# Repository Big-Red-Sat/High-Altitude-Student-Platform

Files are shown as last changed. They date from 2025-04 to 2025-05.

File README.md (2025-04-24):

This repository contains the trials and tribulations UNL's Aerospace eXperimental Payload (AXP) team has gone through for the National Aeronautics and Space Administration (NASA) 
and Louisiana State University's (LSU) High Altitude Student Platform (HASP) program. AXP partnered with the National Renewable Energy Laboratory (NREL) to test their 
experimental solar cells called perovskite solar cells (PSCs).

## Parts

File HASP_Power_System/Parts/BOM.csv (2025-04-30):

Reference | Qty | Value | Footprint | Datasheet
C1 | 1 | 10uF | Capacitor_SMD:C_1210_3225Metric
C2 | 1 | 100nF | Capacitor_SMD:C_0805_2012Metric
C3 | 1 | KRM55TR71H226MH01K | KRM55TR71H226MH01K:CAPC6153X500N
C4 | 1 | 10uF | Capacitor_SMD:C_1206_3216Metric
C5 | 1 | 0.47uF | Capacitor_SMD:C_0805_2012Metric
C6 | 1 | 33uF | Capacitor_SMD:C_1206_3216Metric | https://www.digikey.com/en/products/detail/kyocera-avx/TPSA336K006R0600/563859
C7,C8 | 2 | 0.1u | Capacitor_SMD:C_0805_2012Metric
D1 | 1 | D_Schottky | mcp16301:schottky_diode_B140-13-F
D2 | 1 | 1N4148 | Diode_SMD:D_SOD-323
J1,J2,J3,J4,J7 | 5 | Conn_01x02 | Connector_Molex:Molex_PicoBlade_53047-0210_1x02_P1.25mm_Vertical
J5 | 1 | Conn_01x02 | Connector_PinHeader_2.54mm:PinHeader_1x02_P2.54mm_Horizontal
J6 | 1 | Conn_01x04 | Connector_Molex:Molex_PicoBlade_53047-0410_1x04_P1.25mm_Vertical
L1 | 1 | 1231AS-H-150M=P3 | 1231AS_H_150M_P3:IND_1231AS-H-150M=P3
R1 | 1 | 51.2k | Resistor_SMD:R_0805_2012Metric
R2 | 1 | 10k | Resistor_SMD:R_0805_2012Metric
U1 | 1 | mcp16301 | mcp16301:mcp16301
U2 | 1 | LM3940IMPX-3.3/NOPB | MP04A | LM3940IMPX-3.3/NOPB
U3 | 1 | Teensy4.1 | Teensy:Teensy41

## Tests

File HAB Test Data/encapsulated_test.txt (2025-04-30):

Created file at epoch: 1157
(Timestamp: 1160) Temperature Readings: [35.48, 30.32, 244.19, 32.90, 31.61, -26.13, 33.23, -21.94], Solar Cell 1: [Voltage: 0.00V, Current: 0.33mA], Solar Cell 2: [Voltage: 0.04V, Current: 0.65mA]
(Timestamp: 1662) Temperature Readings: [20.00, 32.26, 30.97, 26.77, 25.48, 25.16, 30.65, 25.48], Solar Cell 1: [Voltage: 0.00V, Current: 0.65mA], Solar Cell 2: [Voltage: 0.03V, Current: 0.98mA]
(Timestamp: 2164) Temperature Readings: [20.32, 25.16, 30.97, 24.52, 31.29, 27.42, 25.48, 27.74], Solar Cell 1: [Voltage: 0.00V, Current: 0.65mA], Solar Cell 2: [Voltage: 0.04V, Current: 0.65mA]
(Timestamp: 2667) Temperature Readings: [12.58, 37.42, 30.65, 26.13, 28.39, 26.77, 30.32, 26.77], Solar Cell 1: [Voltage: 0.00V, Current: 0.65mA], Solar Cell 2: [Voltage: 0.03V, Current: 0.98mA]
(Timestamp: 3169) Temperature Readings: [28.39, 17.74, 31.29, 25.16, 26.13, 29.03, 25.81, 25.81], Solar Cell 1: [Voltage: 0.00V, Current: 0.65mA], Solar Cell 2: [Voltage: 0.04V, Current: 0.65mA]
(Timestamp: 3672) Temperature Readings: [14.19, 34.19, 30.65, 25.81, 28.39, 26.77, 28.71, 25.81], Solar Cell 1: [Voltage: 0.00V, Current: 0.65mA], Solar Cell 2: [Voltage: 0.04V, Current: 0.65mA]
(Timestamp: 4174) Temperature Readings: [12.58, 33.23, 30.00, 25.16, 30.65, 26.45, 27.10, 25.48], Solar Cell 1: [Voltage: 0.00V, Current: 0.65mA], Solar Cell 2: [Voltage: 0.04V, Current: 0.98mA]
(Timestamp: 4677) Temperature Readings: [38.71, 18.39, 29.35, 25.48, 24.84, 27.10, 25.48, 24.84], Solar Cell 1: [Voltage: 0.01V, Current: 0.65mA], Solar Cell 2: [Voltage: 0.04V, Current: 0.98mA]
(Timestamp: 5180) Temperature Readings: [16.13, 30.32, 29.35, 24.52, 32.26, 26.13, 26.13, 25.48], Solar Cell 1: [Voltage: 0.00V, Current: 0.65mA], Solar Cell 2: [Voltage: 0.04V, Current: 0.65mA]
(Timestamp: 5682) Temperature Readings: [11.29, 42.90, 29.35, 25.81, 28.71, 25.48, 29.35, 24.84], Solar Cell 1: [Voltage: 0.00V, Current: 0.65mA], Solar Cell 2: [Voltage: 0.03V, Current: 0.65mA]
(Timestamp: 6185) Temperature Readings: [18.06, 28.06, 30.32, 24.84, 31.61, 26.77, 26.13, 25.48], Solar Cell 1: [Voltage: 0.00V, Current: 0.65mA], Solar Cell 2: [Voltage: 0.04V, Current: 0.98mA]
(Timestamp: 6691) Temperature Readings: [36.13, 24.19, 29.35, 27.10, 24.84, 26.45, 26.77, 24.19], Solar Cell 1: [Voltage: 0.00V, Current: 0.65mA], Solar Cell 2: [Voltage: 0.04V, Current: 0.98mA]
(Timestamp: 7193) Temperature Readings: [22.58, 19.68, 29.03, 24.84, 28.06, 25.81, 25.48, 24.84], Solar Cell 1: [Voltage: 0.00V, Current: 0.65mA], Solar Cell 2: [Voltage: 0.04V, Current: 0.65mA]
(Timestamp: 7696) Temperature Readings: [16.77, 38.06, 28.39, 26.45, 25.81, 23.87, 29.68, 24.19], Solar Cell 1: [Voltage: 0.00V, Current: 0.65mA], Solar Cell 2: [Voltage: 0.04V, Current: 0.98mA]
(Timestamp: 8198) Temperature Readings: [17.74, 38.06, 28.39, 26.77, 25.81, 23.87, 29.03, 23.55], Solar Cell 1: [Voltage: 0.00V, Current: 0.65mA], Solar Cell 2: [Voltage: 0.04V, Current: 0.65mA]
(Timestamp: 8701) Temperature Readings: [11.29, 42.26, 29.35, 26.13, 27.74, 26.13, 29.35, 28.39], Solar Cell 1: [Voltage: 1.99V, Current: 3.26mA], Solar Cell 2: [Voltage: 0.97V, Current: 85.22mA]
(Timestamp: 9204) Temperature Readings: [21.61, 26.77, 29.35, 26.77, 25.16, 24.52, 29.68, 24.19], Solar Cell 1: [Voltage: 2.12V, Current: 3.92mA], Solar Cell 2: [Voltage: 1.72V, Current: 4.24mA]
(Timestamp: 9706) Temperature Readings: [28.71, 21.61, 30.00, 24.84, 27.42, 26.45, 27.10, 25.48], Solar Cell 1: [Voltage: 2.60V, Current: 4.24mA], Solar Cell 2: [Voltage: 2.48V, Current: 5.22mA]
(Timestamp: 10209) Temperature Readings: [38.71, 18.39, 29.03, 25.16, 27.10, 26.13, 27.10, 24.52], Solar Cell 1: [Voltage: 2.61V, Current: 4.24mA], Solar Cell 2: [Voltage: 2.10V, Current: 4.90mA]
(Timestamp: 10711) Temperature Readings: [17.74, 26.13, 27.74, 25.48, 29.35, 25.16, 25.81, 24.19], Solar Cell 1: [Voltage: 1.99V, Current: 3.26mA], Solar Cell 2: [Voltage: 0.57V, Current: 38.20mA]
(Timestamp: 11213) Temperature Readings: [36.77, 21.61, 28.06, 26.77, 24.19, 24.19, 26.77, 23.55], Solar Cell 1: [Voltage: 2.50V, Current: 4.24mA], Solar Cell 2: [Voltage: 2.29V, Current: 5.22mA]
(Timestamp: 11716) Temperature Readings: [29.35, 27.10, 27.74, 27.10, 25.16, 24.52, 27.42, 23.87], Solar Cell 1: [Voltage: 2.74V, Current: 4.24mA], Solar Cell 2: [Voltage: 2.50V, Current: 5.55mA]
(Timestamp: 12222) Temperature Readings: [20.32, 29.35, 29.35, 24.84, 31.29, 25.48, 25.81, 24.52], Solar Cell 1: [Voltage: 2.44V, Current: 4.24mA], Solar Cell 2: [Voltage: 2.14V, Current: 5.22mA]
(Timestamp: 12724) Temperature Readings: [33.87, 21.29, 29.35, 26.45, 24.84, 25.48, 25.81, 24.19], Solar Cell 1: [Voltage: 2.74V, Current: 4.24mA], Solar Cell 2: [Voltage: 2.54V, Current: 5.55mA]
(Timestamp: 13226) Temperature Readings: [22.26, 32.58, 28.39, 26.77, 26.13, 25.16, 28.39, 23.87], Solar Cell 1: [Voltage: 2.72V, Current: 4.24mA], Solar Cell 2: [Voltage: 2.17V, Current: 4.90mA]
(Timestamp: 13729) Temperature Readings: [18.71, 26.45, 27.74, 25.16, 29.03, 24.52, 25.48, 24.19], Solar Cell 1: [Voltage: 2.05V, Current: 3.59mA], Solar Cell 2: [Voltage: 0.64V, Current: 47.02mA]
(Timestamp: 14232) Temperature Readings: [35.81, 25.16, 27.42, 27.42, 25.48, 24.84, 28.06, 23.55], Solar Cell 1: [Voltage: 2.65V, Current: 4.24mA], Solar Cell 2: [Voltage: 2.43V, Current: 5.55mA]
(Timestamp: 14734) Temperature Readings: [16.77, 36.77, 28.06, 25.48, 29.03, 24.52, 27.74, 24.52], Solar Cell 1: [Voltage: 2.80V, Current: 4.24mA], Solar Cell 2: [Voltage: 2.54V, Current: 5.55mA]
(Timestamp: 15237) Temperature Readings: [21.61, 23.55, 29.03, 24.84, 30.32, 25.48, 25.48, 27.42], Solar Cell 1: [Voltage: 2.49V, Current: 3.92mA], Solar Cell 2: [Voltage: 0.95V, Current: 82.93mA]
(Timestamp: 15739) Temperature Readings: [14.84, 32.26, 28.71, 24.84, 29.68, 24.52, 27.10, 24.19], Solar Cell 1: [Voltage: 2.43V, Current: 4.24mA], Solar Cell 2: [Voltage: 1.75V, Current: 4.57mA]
(Timestamp: 16242) Temperature Readings: [41.29, 21.61, 28.71, 25.48, 25.81, 25.48, 26.77, 24.19], Solar Cell 1: [Voltage: 2.79V, Current: 4.57mA], Solar Cell 2: [Voltage: 2.15V, Current: 4.90mA]
(Timestamp: 16744) Temperature Readings: [34.19, 15.48, 28.39, 25.16, 25.81, 25.81, 25.48, 23.87], Solar Cell 1: [Voltage: 2.74V, Current: 4.57mA], Solar Cell 2: [Voltage: 1.82V, Current: 4.57mA]
(Timestamp: 17247) Temperature Readings: [20.32, 34.52, 26.77, 26.13, 26.45, 22.58, 29.68, 23.23], Solar Cell 1: [Voltage: 2.09V, Current: 3.92mA], Solar Cell 2: [Voltage: 0.75V, Current: 61.06mA]
(Timestamp: 17750) Temperature Readings: [34.19, 25.81, 27.10, 26.45, 25.16, 23.55, 27.42, 22.58], Solar Cell 1: [Voltage: 2.71V, Current: 4.24mA], Solar Cell 2: [Voltage: 2.06V, Current: 4.90mA]
(Timestamp: 18256) Temperature Readings: [12.90, 36.45, 28.06, 25.48, 31.29, 24.52, 27.42, 24.52], Solar Cell 1: [Voltage: 2.08V, Current: 3.92mA], Solar Cell 2: [Voltage: 0.69V, Current: 53.22mA]
(Timestamp: 18758) Temperature Readings: [31.94, 21.29, 28.71, 26.77, 25.48, 24.52, 26.45, 23.23], Solar Cell 1: [Voltage: 2.70V, Current: 4.24mA], Solar Cell 2: [Voltage: 2.00V, Current: 4.90mA]
(Timestamp: 19261) Temperature Readings: [39.03, 19.35, 28.39, 26.77, 25.81, 24.52, 26.77, 23.23], Solar Cell 1: [Voltage: 2.82V, Current: 4.57mA], Solar Cell 2: [Voltage: 2.00V, Current: 4.57mA]
(Timestamp: 19763) Temperature Readings: [34.52, 25.16, 27.10, 26.77, 25.48, 23.87, 28.06, 23.87], Solar Cell 1: [Voltage: 2.46V, Current: 3.92mA], Solar Cell 2: [Voltage: 0.86V, Current: 71.50mA]
(Timestamp: 20266) Temperature Readings: [27.10, 28.06, 26.77, 27.42, 25.16, 22.90, 28.06, 22.58], Solar Cell 1: [Voltage: 2.49V, Current: 4.24mA], Solar Cell 2: [Voltage: 1.82V, Current: 4.57mA]
(Timestamp: 20768) Temperature Readings: [15.16, 32.90, 27.42, 26.13, 31.94, 22.90, 27.74, 23.55], Solar Cell 1: [Voltage: 2.79V, Current: 4.57mA], Solar Cell 2: [Voltage: 2.14V, Current: 4.90mA]
(Timestamp: 21271) Temperature Readings: [37.42, 21.29, 28.06, 25.16, 23.23, 23.23, 26.13, 23.23], Solar Cell 1: [Voltage: 2.77V, Current: 4.24mA], Solar Cell 2: [Voltage: 1.94V, Current: 4.90mA]
(Timestamp: 21773) Temperature Readings: [14.84, 37.42, 27.42, 26.13, 27.74, 22.90, 29.35, 23.23], Solar Cell 1: [Voltage: 2.17V, Current: 3.59mA], Solar Cell 2: [Voltage: 0.59V, Current: 39.18mA]
(Timestamp: 22276) Temperature Readings: [12.26, 32.26, 28.39, 25.16, 31.29, 23.55, 27.10, 23.55], Solar Cell 1: [Voltage: 2.63V, Current: 4.24mA], Solar Cell 2: [Voltage: 1.97V, Current: 4.57mA]
(Timestamp: 22778) Temperature Readings: [25.16, 21.61, 28.71, 24.84, 29.03, 24.84, 26.45, 23.87], Solar Cell 1: [Voltage: 2.81V, Current: 4.57mA], Solar Cell 2: [Voltage: 2.06V, Current: 4.90mA]
(Timestamp: 23280) Temperature Readings: [38.06, 24.52, 27.10, 27.74, 24.52, 23.55, 26.77, 22.58], Solar Cell 1: [Voltage: 2.70V, Current: 4.24mA], Solar Cell 2: [Voltage: 1.61V, Current: 4.24mA]
(Timestamp: 23783) Temperature Readings: [30.32, 17.74, 26.77, 25.16, 25.48, 23.87, 25.81, 23.23], Solar Cell 1: [Voltage: 2.08V, Current: 3.92mA], Solar Cell 2: [Voltage: 0.77V, Current: 63.34mA]
(Timestamp: 24289) Temperature Readings: [23.55, 17.74, 27.74, 24.84, 27.42, 23.55, 24.84, 23.23], Solar Cell 1: [Voltage: 2.74V, Current: 4.24mA], Solar Cell 2: [Voltage: 1.81V, Current: 4.57mA]
(Timestamp: 24791) Temperature Readings: [11.61, 42.26, 27.74, 26.13, 27.74, 22.90, 29.03, 23.55], Solar Cell 1: [Voltage: 2.06V, Current: 3.92mA], Solar Cell 2: [Voltage: 0.70V, Current: 55.18mA]
(Timestamp: 25294) Temperature Readings: [13.23, 30.00, 28.06, 26.13, 30.32, 24.19, 27.10, 23.87], Solar Cell 1: [Voltage: 2.69V, Current: 4.24mA], Solar Cell 2: [Voltage: 2.52V, Current: 5.55mA]
(Timestamp: 25796) Temperature Readings: [36.45, 23.23, 27.74, 25.81, 25.48, 24.84, 27.74, 23.55], Solar Cell 1: [Voltage: 2.79V, Current: 4.57mA], Solar Cell 2: [Voltage: 2.62V, Current: 5.55mA]
(Timestamp: 26299) Temperature Readings: [16.13, 26.77, 26.77, 25.48, 29.35, 22.90, 26.13, 24.52], Solar Cell 1: [Voltage: 2.45V, Current: 3.92mA], Solar Cell 2: [Voltage: 0.95V, Current: 82.93mA]
(Timestamp: 26802) Temperature Readings: [33.23, 28.71, 26.13, 26.77, 24.84, 22.26, 26.77, 21.29], Solar Cell 1: [Voltage: 2.43V, Current: 4.24mA], Solar Cell 2: [Voltage: 2.05V, Current: 4.90mA]
(Timestamp: 27304) Temperature Readings: [37.74, 23.23, 26.77, 26.13, 23.87, 22.90, 25.81, 22.90], Solar Cell 1: [Voltage: 2.74V, Current: 4.57mA], Solar Cell 2: [Voltage: 2.66V, Current: 5.55mA]
(Timestamp: 27807) Temperature Readings: [13.87, 32.58, 27.10, 25.16, 30.65, 22.90, 26.45, 23.23], Solar Cell 1: [Voltage: 0.96V, Current: 99.91mA], Solar Cell 2: [Voltage: 2.07V, Current: 4.90mA]
(Timestamp: 28309) Temperature Readings: [12.26, 35.16, 27.42, 25.48, 30.97, 22.90, 27.74, 23.55], Solar Cell 1: [Voltage: 0.78V, Current: 85.22mA], Solar Cell 2: [Voltage: 0.76V, Current: 62.36mA]
(Timestamp: 28812) Temperature Readings: [14.84, 32.58, 27.74, 25.81, 31.29, 24.19, 26.77, 23.87], Solar Cell 1: [Voltage: 1.00V, Current: 111.66mA], Solar Cell 2: [Voltage: 2.31V, Current: 5.22mA]
(Timestamp: 29314) Temperature Readings: [38.06, 17.74, 27.74, 25.48, 24.84, 23.55, 25.81, 23.23], Solar Cell 1: [Voltage: 1.06V, Current: 111.99mA], Solar Cell 2: [Voltage: 2.19V, Current: 4.90mA]
(Timestamp: 29817) Temperature Readings: [30.65, 15.81, 26.77, 25.16, 25.81, 23.55, 25.81, 23.87], Solar Cell 1: [Voltage: 0.89V, Current: 87.18mA], Solar Cell 2: [Voltage: 0.85V, Current: 71.18mA]
(Timestamp: 30323) Temperature Readings: [39.35, 20.32, 26.77, 26.13, 24.19, 22.90, 25.48, 22.26], Solar Cell 1: [Voltage: 1.06V, Current: 111.99mA], Solar Cell 2: [Voltage: 2.37V, Current: 5.22mA]
(Timestamp: 30826) Temperature Readings: [34.52, 25.81, 27.10, 26.77, 24.84, 23.23, 27.10, 23.23], Solar Cell 1: [Voltage: 0.90V, Current: 88.48mA], Solar Cell 2: [Voltage: 0.89V, Current: 75.75mA]
(Timestamp: 31328) Temperature Readings: [23.23, 32.58, 27.10, 26.77, 24.84, 22.26, 28.71, 22.26], Solar Cell 1: [Voltage: 0.90V, Current: 107.09mA], Solar Cell 2: [Voltage: 1.81V, Current: 4.57mA]
(Timestamp: 31830) Temperature Readings: [21.61, 20.32, 28.39, 24.52, 28.39, 23.55, 25.48, 23.55], Solar Cell 1: [Voltage: 1.05V, Current: 108.40mA], Solar Cell 2: [Voltage: 2.39V, Current: 5.22mA]
(Timestamp: 32333) Temperature Readings: [27.42, 21.94, 27.42, 25.48, 27.74, 23.23, 26.45, 23.23], Solar Cell 1: [Voltage: 1.06V, Current: 111.01mA], Solar Cell 2: [Voltage: 2.23V, Current: 4.90mA]
(Timestamp: 32835) Temperature Readings: [28.06, 16.45, 26.45, 24.84, 27.10, 22.90, 26.45, 22.26], Solar Cell 1: [Voltage: 0.83V, Current: 80.32mA], Solar Cell 2: [Voltage: 0.59V, Current: 40.16mA]
(Timestamp: 33338) Temperature Readings: [26.45, 21.61, 26.45, 25.48, 24.84, 22.58, 25.48, 22.90], Solar Cell 1: [Voltage: 0.95V, Current: 110.68mA], Solar Cell 2: [Voltage: 2.17V, Current: 4.90mA]
(Timestamp: 33840) Temperature Readings: [17.10, 36.77, 26.45, 25.48, 31.61, 21.29, 29.35, 22.58], Solar Cell 1: [Voltage: 1.06V, Current: 95.01mA], Solar Cell 2: [Voltage: 2.42V, Current: 5.22mA]
(Timestamp: 34343) Temperature Readings: [36.13, 25.16, 27.10, 26.13, 25.16, 22.58, 25.81, 20.97], Solar Cell 1: [Voltage: 1.02V, Current: 105.46mA], Solar Cell 2: [Voltage: 1.83V, Current: 4.57mA]
(Timestamp: 34845) Temperature Readings: [25.81, 21.94, 27.74, 25.48, 28.39, 24.19, 26.45, 24.84], Solar Cell 1: [Voltage: 0.83V, Current: 95.99mA], Solar Cell 2: [Voltage: 1.04V, Current: 96.64mA]
(Timestamp: 35348) Temperature Readings: [22.58, 32.58, 27.42, 26.13, 26.45, 21.61, 28.71, 22.58], Solar Cell 1: [Voltage: 1.04V, Current: 96.32mA], Solar Cell 2: [Voltage: 2.39V, Current: 5.22mA]
(Timestamp: 35854) Temperature Readings: [39.35, 23.87, 25.81, 26.77, 25.81, 22.58, 27.42, 23.55], Solar Cell 1: [Voltage: 0.81V, Current: 95.01mA], Solar Cell 2: [Voltage: 0.98V, Current: 89.46mA]
(Timestamp: 36356) Temperature Readings: [34.52, 16.13, 26.45, 26.45, 24.52, 22.58, 26.13, 22.90], Solar Cell 1: [Voltage: 1.04V, Current: 107.42mA], Solar Cell 2: [Voltage: 2.35V, Current: 5.22mA]
(Timestamp: 36859) Temperature Readings: [36.77, 20.00, 27.10, 24.84, 24.52, 22.58, 24.52, 21.94], Solar Cell 1: [Voltage: 1.07V, Current: 111.66mA], Solar Cell 2: [Voltage: 1.94V, Current: 4.57mA]
(Timestamp: 37362) Temperature Readings: [24.84, 14.84, 27.42, 25.16, 28.71, 23.23, 24.84, 22.90], Solar Cell 1: [Voltage: 0.85V, Current: 82.28mA], Solar Cell 2: [Voltage: 0.62V, Current: 43.10mA]
(Timestamp: 37864) Temperature Readings: [33.87, 24.84, 27.10, 26.45, 24.52, 22.58, 28.71, 22.26], Solar Cell 1: [Voltage: 0.98V, Current: 111.99mA], Solar Cell 2: [Voltage: 2.17V, Current: 4.90mA]
(Timestamp: 38367) Temperature Readings: [17.10, 41.61, 26.77, 26.13, 27.10, 21.61, 29.03, 22.26], Solar Cell 1: [Voltage: 1.08V, Current: 75.42mA], Solar Cell 2: [Voltage: 2.35V, Current: 5.22mA]
(Timestamp: 38869) Temperature Readings: [22.90, 23.23, 26.77, 25.16, 26.77, 22.58, 25.48, 22.58], Solar Cell 1: [Voltage: 0.97V, Current: 98.93mA], Solar Cell 2: [Voltage: 1.35V, Current: 61.71mA]
(Timestamp: 39372) Temperature Readings: [21.61, 31.94, 25.48, 26.45, 24.84, 20.97, 28.71, 21.61], Solar Cell 1: [Voltage: 0.89V, Current: 107.09mA], Solar Cell 2: [Voltage: 1.61V, Current: 4.24mA]
(Timestamp: 39874) Temperature Readings: [25.48, 21.94, 26.13, 26.45, 24.52, 22.90, 25.16, 22.26], Solar Cell 1: [Voltage: 1.07V, Current: 66.93mA], Solar Cell 2: [Voltage: 2.35V, Current: 5.22mA]
(Timestamp: 40377) Temperature Readings: [12.90, 39.68, 26.45, 25.81, 27.74, 21.29, 29.68, 22.26], Solar Cell 1: [Voltage: 1.04V, Current: 109.38mA], Solar Cell 2: [Voltage: 2.03V, Current: 4.57mA]
(Timestamp: 40880) Temperature Readings: [20.00, 25.48, 27.42, 24.84, 31.29, 22.26, 25.48, 23.23], Solar Cell 1: [Voltage: 0.81V, Current: 89.13mA], Solar Cell 2: [Voltage: 0.74V, Current: 59.75mA]
(Timestamp: 41382) Temperature Readings: [20.32, 27.74, 27.10, 24.84, 30.00, 22.58, 25.48, 23.23], Solar Cell 1: [Voltage: 1.03V, Current: 77.71mA], Solar Cell 2: [Voltage: 2.29V, Current: 5.22mA]
(Timestamp: 41888) Temperature Readings: [38.71, 19.35, 25.81, 25.16, 26.13, 21.94, 26.77, 22.58], Solar Cell 1: [Voltage: 0.81V, Current: 87.18mA], Solar Cell 2: [Voltage: 0.68V, Current: 52.89mA]
(Timestamp: 42390) Temperature Readings: [26.45, 15.81, 26.13, 25.16, 27.10, 22.26, 24.84, 22.26], Solar Cell 1: [Voltage: 1.01V, Current: 90.44mA], Solar Cell 2: [Voltage: 2.26V, Current: 5.22mA]
(Timestamp: 42893) Temperature Readings: [25.16, 21.29, 26.13, 25.48, 25.81, 21.94, 24.84, 21.29], Solar Cell 1: [Voltage: 1.08V, Current: 65.95mA], Solar Cell 2: [Voltage: 2.32V, Current: 5.22mA]
(Timestamp: 43395) Temperature Readings: [32.90, 15.48, 27.42, 25.48, 25.16, 23.55, 25.16, 24.84], Solar Cell 1: [Voltage: 0.95V, Current: 96.32mA], Solar Cell 2: [Voltage: 1.11V, Current: 99.91mA]
(Timestamp: 43898) Temperature Readings: [39.68, 19.35, 27.42, 25.81, 24.19, 22.26, 25.48, 22.26], Solar Cell 1: [Voltage: 0.88V, Current: 106.11mA], Solar Cell 2: [Voltage: 1.53V, Current: 4.57mA]
(Timestamp: 44400) Temperature Readings: [17.10, 32.90, 27.10, 25.81, 31.29, 21.94, 28.06, 22.58], Solar Cell 1: [Voltage: 1.06V, Current: 63.34mA], Solar Cell 2: [Voltage: 2.14V, Current: 4.90mA]
(Timestamp: 44903) Temperature Readings: [36.13, 28.39, 26.45, 26.77, 24.84, 22.26, 26.77, 21.61], Solar Cell 1: [Voltage: 1.06V, Current: 111.66mA], Solar Cell 2: [Voltage: 1.94V, Current: 4.57mA]
(Timestamp: 45405) Temperature Readings: [32.90, 24.19, 25.16, 27.10, 25.48, 21.29, 28.39, 20.97], Solar Cell 1: [Voltage: 0.80V, Current: 83.91mA], Solar Cell 2: [Voltage: 0.62V, Current: 44.08mA]
(Timestamp: 45908) Temperature Readings: [26.13, 19.03, 26.13, 25.16, 27.74, 21.94, 24.84, 22.26], Solar Cell 1: [Voltage: 1.02V, Current: 72.16mA], Solar Cell 2: [Voltage: 2.54V, Current: 5.55mA]
(Timestamp: 46410) Temperature Readings: [25.81, 30.00, 25.48, 26.77, 24.84, 20.32, 28.39, 21.29], Solar Cell 1: [Voltage: 1.08V, Current: 66.28mA], Solar Cell 2: [Voltage: 2.62V, Current: 5.55mA]
(Timestamp: 46913) Temperature Readings: [12.58, 40.32, 26.45, 25.81, 29.68, 21.94, 28.71, 22.90], Solar Cell 1: [Voltage: 0.90V, Current: 89.46mA], Solar Cell 2: [Voltage: 0.81V, Current: 65.95mA]
(Timestamp: 47415) Temperature Readings: [36.77, 18.71, 27.10, 25.48, 24.52, 22.26, 26.45, 22.58], Solar Cell 1: [Voltage: 0.95V, Current: 111.99mA], Solar Cell 2: [Voltage: 2.27V, Current: 5.22mA]
(Timestamp: 47922) Temperature Readings: [19.03, 37.10, 25.48, 26.45, 26.13, 20.65, 29.03, 21.94], Solar Cell 1: [Voltage: 0.86V, Current: 85.22mA], Solar Cell 2: [Voltage: 0.67V, Current: 48.65mA]
(Timestamp: 48424) Temperature Readings: [35.81, 20.32, 25.81, 25.16, 25.16, 22.26, 25.16, 21.94], Solar Cell 1: [Voltage: 0.97V, Current: 111.01mA], Solar Cell 2: [Voltage: 2.08V, Current: 4.90mA]
(Timestamp: 48927) Temperature Readings: [18.06, 30.32, 25.48, 25.81, 33.23, 20.97, 26.77, 21.61], Solar Cell 1: [Voltage: 1.08V, Current: 51.59mA], Solar Cell 2: [Voltage: 2.30V, Current: 5.22mA]
(Timestamp: 49429) Temperature Readings: [30.32, 13.23, 27.10, 25.16, 26.13, 22.26, 24.52, 23.23], Solar Cell 1: [Voltage: 0.97V, Current: 99.58mA], Solar Cell 2: [Voltage: 1.30V, Current: 115.58mA]
(Timestamp: 49932) Temperature Readings: [22.58, 23.23, 27.10, 25.16, 29.35, 22.26, 26.13, 22.58], Solar Cell 1: [Voltage: 0.90V, Current: 110.03mA], Solar Cell 2: [Voltage: 1.66V, Current: 4.24mA]
(Timestamp: 50434) Temperature Readings: [34.52, 19.68, 26.77, 26.13, 25.48, 22.90, 25.16, 21.61], Solar Cell 1: [Voltage: 1.08V, Current: 36.24mA], Solar Cell 2: [Voltage: 2.29V, Current: 5.22mA]
(Timestamp: 50937) Temperature Readings: [28.06, 28.39, 26.13, 27.10, 25.48, 21.61, 29.35, 21.61], Solar Cell 1: [Voltage: 1.05V, Current: 110.03mA], Solar Cell 2: [Voltage: 1.89V, Current: 4.57mA]
(Timestamp: 51440) Temperature Readings: [26.45, 19.68, 25.81, 25.48, 27.10, 21.94, 25.48, 22.90], Solar Cell 1: [Voltage: 0.82V, Current: 97.62mA], Solar Cell 2: [Voltage: 0.97V, Current: 89.46mA]
(Timestamp: 51942) Temperature Readings: [22.90, 25.16, 25.81, 24.84, 31.94, 21.29, 25.81, 21.61], Solar Cell 1: [Voltage: 1.05V, Current: 45.38mA], Solar Cell 2: [Voltage: 2.23V, Current: 4.90mA]
(Timestamp: 52444) Temperature Readings: [16.45, 30.97, 25.48, 26.13, 28.06, 20.65, 27.74, 21.29], Solar Cell 1: [Voltage: 1.09V, Current: 54.20mA], Solar Cell 2: [Voltage: 2.19V, Current: 4.90mA]
(Timestamp: 52947) Temperature Readings: [16.45, 30.00, 26.45, 24.84, 31.61, 21.94, 26.13, 23.55], Solar Cell 1: [Voltage: 0.90V, Current: 91.09mA], Solar Cell 2: [Voltage: 0.86V, Current: 70.85mA]
(Timestamp: 53453) Temperature Readings: [35.81, 21.61, 26.45, 26.45, 25.48, 22.26, 25.81, 20.97], Solar Cell 1: [Voltage: 1.08V, Current: 64.97mA], Solar Cell 2: [Voltage: 2.38V, Current: 5.22mA]
(Timestamp: 53955) Temperature Readings: [25.48, 18.39, 26.13, 24.84, 27.10, 21.61, 26.13, 22.90], Solar Cell 1: [Voltage: 0.91V, Current: 92.07mA], Solar Cell 2: [Voltage: 0.87V, Current: 72.81mA]
(Timestamp: 54457) Temperature Readings: [21.61, 29.35, 25.48, 24.84, 31.61, 20.97, 26.13, 21.94], Solar Cell 1: [Voltage: 0.92V, Current: 111.34mA], Solar Cell 2: [Voltage: 1.95V, Current: 4.57mA]
(Timestamp: 54960) Temperature Readings: [22.26, 20.00, 25.81, 25.16, 25.48, 21.61, 25.16, 21.94], Solar Cell 1: [Voltage: 1.08V, Current: 38.53mA], Solar Cell 2: [Voltage: 2.43V, Current: 5.22mA]
(Timestamp: 55462) Temperature Readings: [41.61, 21.29, 25.81, 26.13, 23.55, 21.61, 26.45, 20.97], Solar Cell 1: [Voltage: 1.00V, Current: 105.46mA], Solar Cell 2: [Voltage: 1.69V, Current: 4.24mA]
(Timestamp: 55965) Temperature Readings: [12.26, 35.16, 26.77, 24.84, 28.71, 22.26, 27.10, 24.19], Solar Cell 1: [Voltage: 0.85V, Current: 104.48mA], Solar Cell 2: [Voltage: 1.37V, Current: 19.92mA]
(Timestamp: 56468) Temperature Readings: [24.19, 29.03, 26.77, 25.48, 25.48, 20.97, 29.03, 21.29], Solar Cell 1: [Voltage: 1.06V, Current: 39.83mA], Solar Cell 2: [Voltage: 2.40V, Current: 5.22mA]
(Timestamp: 56970) Temperature Readings: [30.65, 29.68, 26.13, 27.10, 25.81, 21.29, 27.74, 21.61], Solar Cell 1: [Voltage: 1.06V, Current: 111.66mA], Solar Cell 2: [Voltage: 2.08V, Current: 4.90mA]
(Timestamp: 57473) Temperature Readings: [23.87, 23.55, 25.48, 25.16, 27.10, 20.97, 25.16, 22.26], Solar Cell 1: [Voltage: 0.80V, Current: 91.42mA], Solar Cell 2: [Voltage: 0.76V, Current: 63.01mA]
(Timestamp: 57975) Temperature Readings: [39.68, 27.10, 23.87, 26.45, 25.81, 21.29, 25.81, 20.00], Solar Cell 1: [Voltage: 1.05V, Current: 39.18mA], Solar Cell 2: [Voltage: 2.39V, Current: 5.22mA]
(Timestamp: 58478) Temperature Readings: [39.68, 18.06, 25.81, 25.81, 24.52, 21.29, 26.13, 21.29], Solar Cell 1: [Voltage: 1.08V, Current: 64.65mA], Solar Cell 2: [Voltage: 2.32V, Current: 5.22mA]
(Timestamp: 58981) Temperature Readings: [29.03, 12.58, 26.77, 25.48, 26.45, 21.94, 25.48, 22.26], Solar Cell 1: [Voltage: 0.84V, Current: 84.89mA], Solar Cell 2: [Voltage: 0.61V, Current: 41.14mA]
(Timestamp: 59487) Temperature Readings: [24.84, 30.32, 26.13, 26.13, 25.16, 20.65, 28.71, 21.94], Solar Cell 1: [Voltage: 1.08V, Current: 82.60mA], Solar Cell 2: [Voltage: 2.27V, Current: 5.22mA]
(Timestamp: 59989) Temperature Readings: [26.77, 28.39, 24.84, 27.10, 25.16, 20.97, 28.39, 20.97], Solar Cell 1: [Voltage: 0.81V, Current: 85.22mA], Solar Cell 2: [Voltage: 0.59V, Current: 40.49mA]
(Timestamp: 60492) Temperature Readings: [38.39, 19.03, 25.48, 25.48, 24.19, 20.97, 25.81, 21.29], Solar Cell 1: [Voltage: 1.03V, Current: 43.75mA], Solar Cell 2: [Voltage: 2.33V, Current: 5.22mA]
(Timestamp: 60994) Temperature Readings: [19.35, 29.68, 25.16, 25.16, 31.94, 21.94, 26.45, 22.26], Solar Cell 1: [Voltage: 1.09V, Current: 41.79mA], Solar Cell 2: [Voltage: 2.37V, Current: 5.22mA]
(Timestamp: 61497) Temperature Readings: [26.13, 16.13, 26.45, 25.16, 27.42, 22.26, 25.48, 22.58], Solar Cell 1: [Voltage: 0.87V, Current: 88.15mA], Solar Cell 2: [Voltage: 0.72V, Current: 54.20mA]
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

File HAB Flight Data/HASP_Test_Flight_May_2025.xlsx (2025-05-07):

Time Since Power On (ms) | Temperature Mounted on Module Inside Payload (C) | Temperature Encapsulated Inside Perovskite (C) | Temperature Internal on Perovskite Enclosure (C) | Temperature Outside Payload on Module Glass (C) | Temperature Behind Module On Aluminum (C) | SolarCell1 Voltage (V) | SolarCell1 Current (mA) | SolarCell2 Voltage (V) | SolarCell2 Current (mA)
1155 | 25.48 | 24.84 | 26.13 | 26.13 | 25.16 | 0.63 | 71.83 | 3.43 | 6.53
1672 | 19.68 | 19.03 | 20 | 19.68 | 19.68 | 0.66 | 77.71 | 3.45 | 6.86
2183 | 19.68 | 19.03 | 20 | 19.68 | 19.68 | 0.66 | 77.71 | 3.45 | 6.53
2694 | 19.68 | 19.03 | 20 | 20 | 19.68 | 0.71 | 83.26 | 3.46 | 6.86
3205 | 19.68 | 19.03 | 20 | 20 | 20 | 0.7 | 82.93 | 3.46 | 6.86
3716 | 19.68 | 18.71 | 20 | 20 | 19.68 | 0.72 | 85.54 | 3.44 | 6.53
4229 | 19.68 | 19.68 | 20.32 | 20.97 | 19.68 | 0.75 | 88.48 | 3.45 | 6.53
4742 | 19.68 | 19.35 | 20.32 | 20.97 | 20 | 0.71 | 84.56 | 3.48 | 6.53
5255 | 19.68 | 19.03 | 20 | 20.32 | 19.68 | 0.65 | 77.38 | 3.52 | 6.86
5769 | 19.68 | 19.03 | 20 | 20 | 19.68 | 0.57 | 68.56 | 3.54 | 6.86
6283 | 19.68 | 19.03 | 20 | 20.32 | 19.68 | 0.6 | 72.81 | 3.52 | 6.86
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

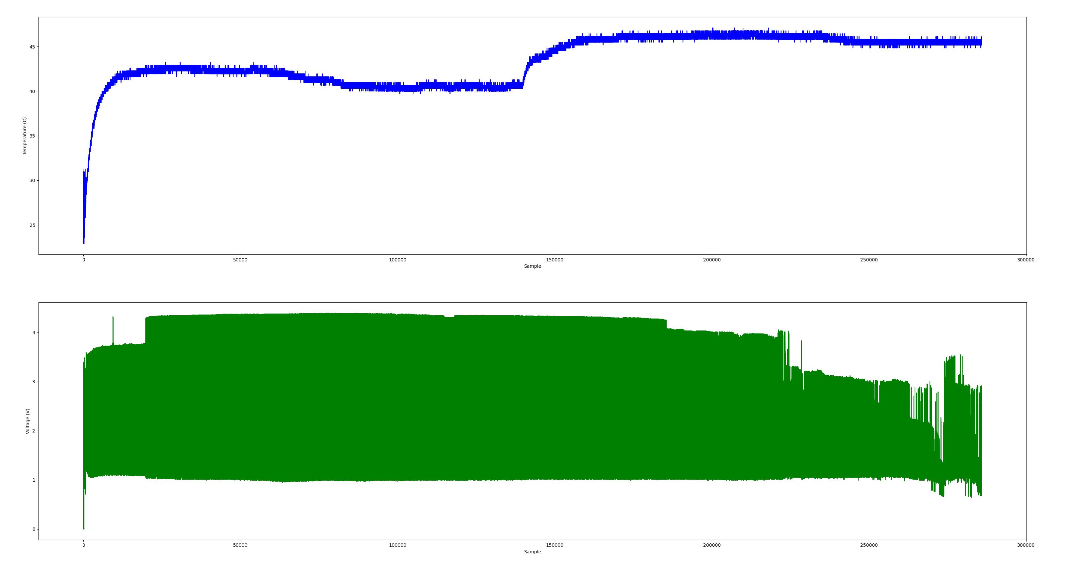
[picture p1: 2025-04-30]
HAB Test Data/Overnight_Test_Voltage_Temperature.png

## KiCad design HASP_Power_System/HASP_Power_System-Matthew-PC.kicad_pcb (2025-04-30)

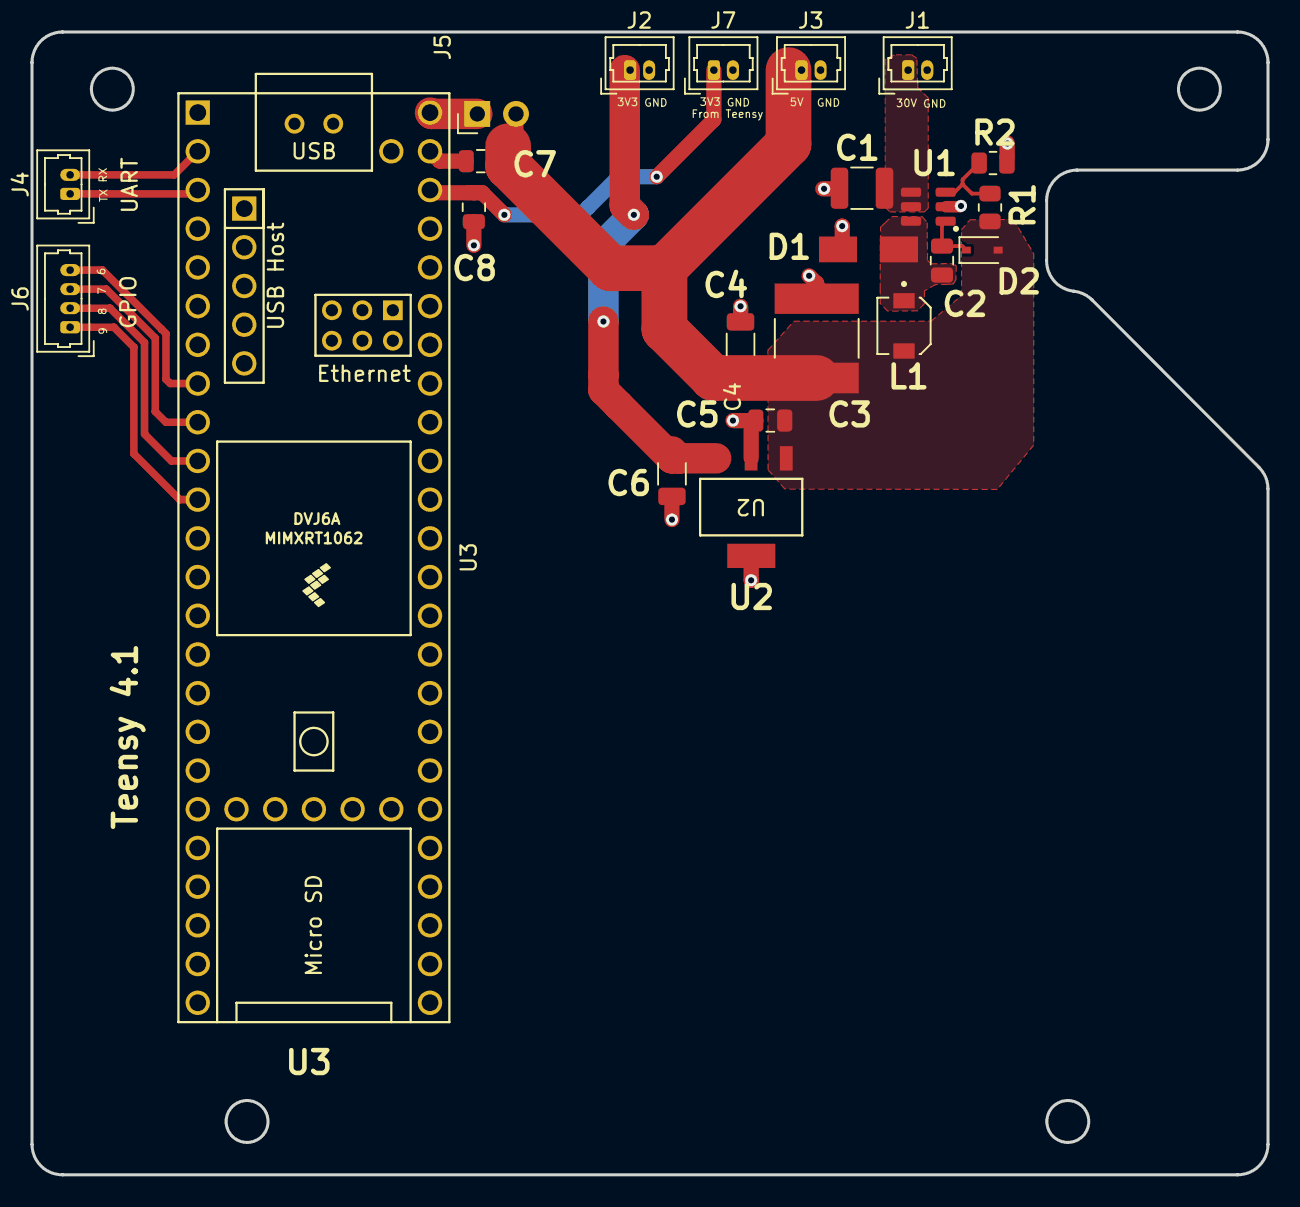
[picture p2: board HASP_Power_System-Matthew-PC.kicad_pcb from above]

Board: 2 copper layers, 81.1 x 75.0 mm, 23 parts (0 on the bottom side), 15 nets.

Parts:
C1: 10uF; C_1210_3225Metric
C2: 100nF; C_0805_2012Metric
C3: KRM55TR71H226MH01K; CAPC6153X500N
C4: 10uF; C_1206_3216Metric
C5: 0.47uF; C_0805_2012Metric
C6: 33uF; C_1206_3216Metric
C7, C8: 0.1u; C_0805_2012Metric
D1: D_Schottky; schottky_diode_B140-13-F
D2: 1N4148; D_SOD-323
J1, J2, J3, J4, J7: Conn_01x02; Molex_PicoBlade_53047-0210_1x02_P1.25mm_Vertical
J5: Conn_01x02; PinHeader_1x02_P2.54mm_Horizontal
J6: Conn_01x04; Molex_PicoBlade_53047-0410_1x04_P1.25mm_Vertical
L1: 1231AS-H-150M=P3; IND_1231AS-H-150M=P3
R1: 51.2k; R_0805_2012Metric
R2: 10k; R_0805_2012Metric
U1: mcp16301
U2: LM3940IMPX-3.3/NOPB; MP04A
U3: Teensy4.1; Teensy41

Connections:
+3V3_LDO: C6.1, J2.1, U2.3 (OUT)
+3V3_Teensy: C8.1, J7.1, U3.46 (3V3)
+5V: C3.1, C4.1, C5.1, C7.1, D2.2 (A), J3.1, J5.2, L1.2, R1.1, U2.1 (IN)
/SW_NODE: C2.2, D1.1 (K), L1.1, U1.6 (SW)
GND: C1.2, C3.2, C4.2, C5.2, C6.2, C7.2, C8.2, D1.2 (A), J1.2, J2.2, J3.2, J7.2, R2.2, U1.2 (GND), U2.2 (GND), U3.1 (GND), U3.34 (GND), U3.47 (GND)
GPIO1: J6.4, U3.8 (6_OUT1D)
GPIO2: J6.3, U3.9 (7_RX2_OUT1A)
GPIO3: J6.2, U3.10 (8_TX2_IN1)
GPIO4: J6.1, U3.11 (9_OUT1C)
unnamed: C2.1, D2.1 (K), U1.1 (Boost)
unnamed: J5.1, U3.48 (VIN)
unnamed: R1.2, R2.1, U1.3 (V_{FB})
RX: J4.2, U3.2 (0_RX1_CRX2_CS1)
TX: J4.1, U3.3 (1_TX1_CTX2_MISO1)
VCC_30: C1.1, J1.1, U1.4 (EN), U1.5 (V_{IN})

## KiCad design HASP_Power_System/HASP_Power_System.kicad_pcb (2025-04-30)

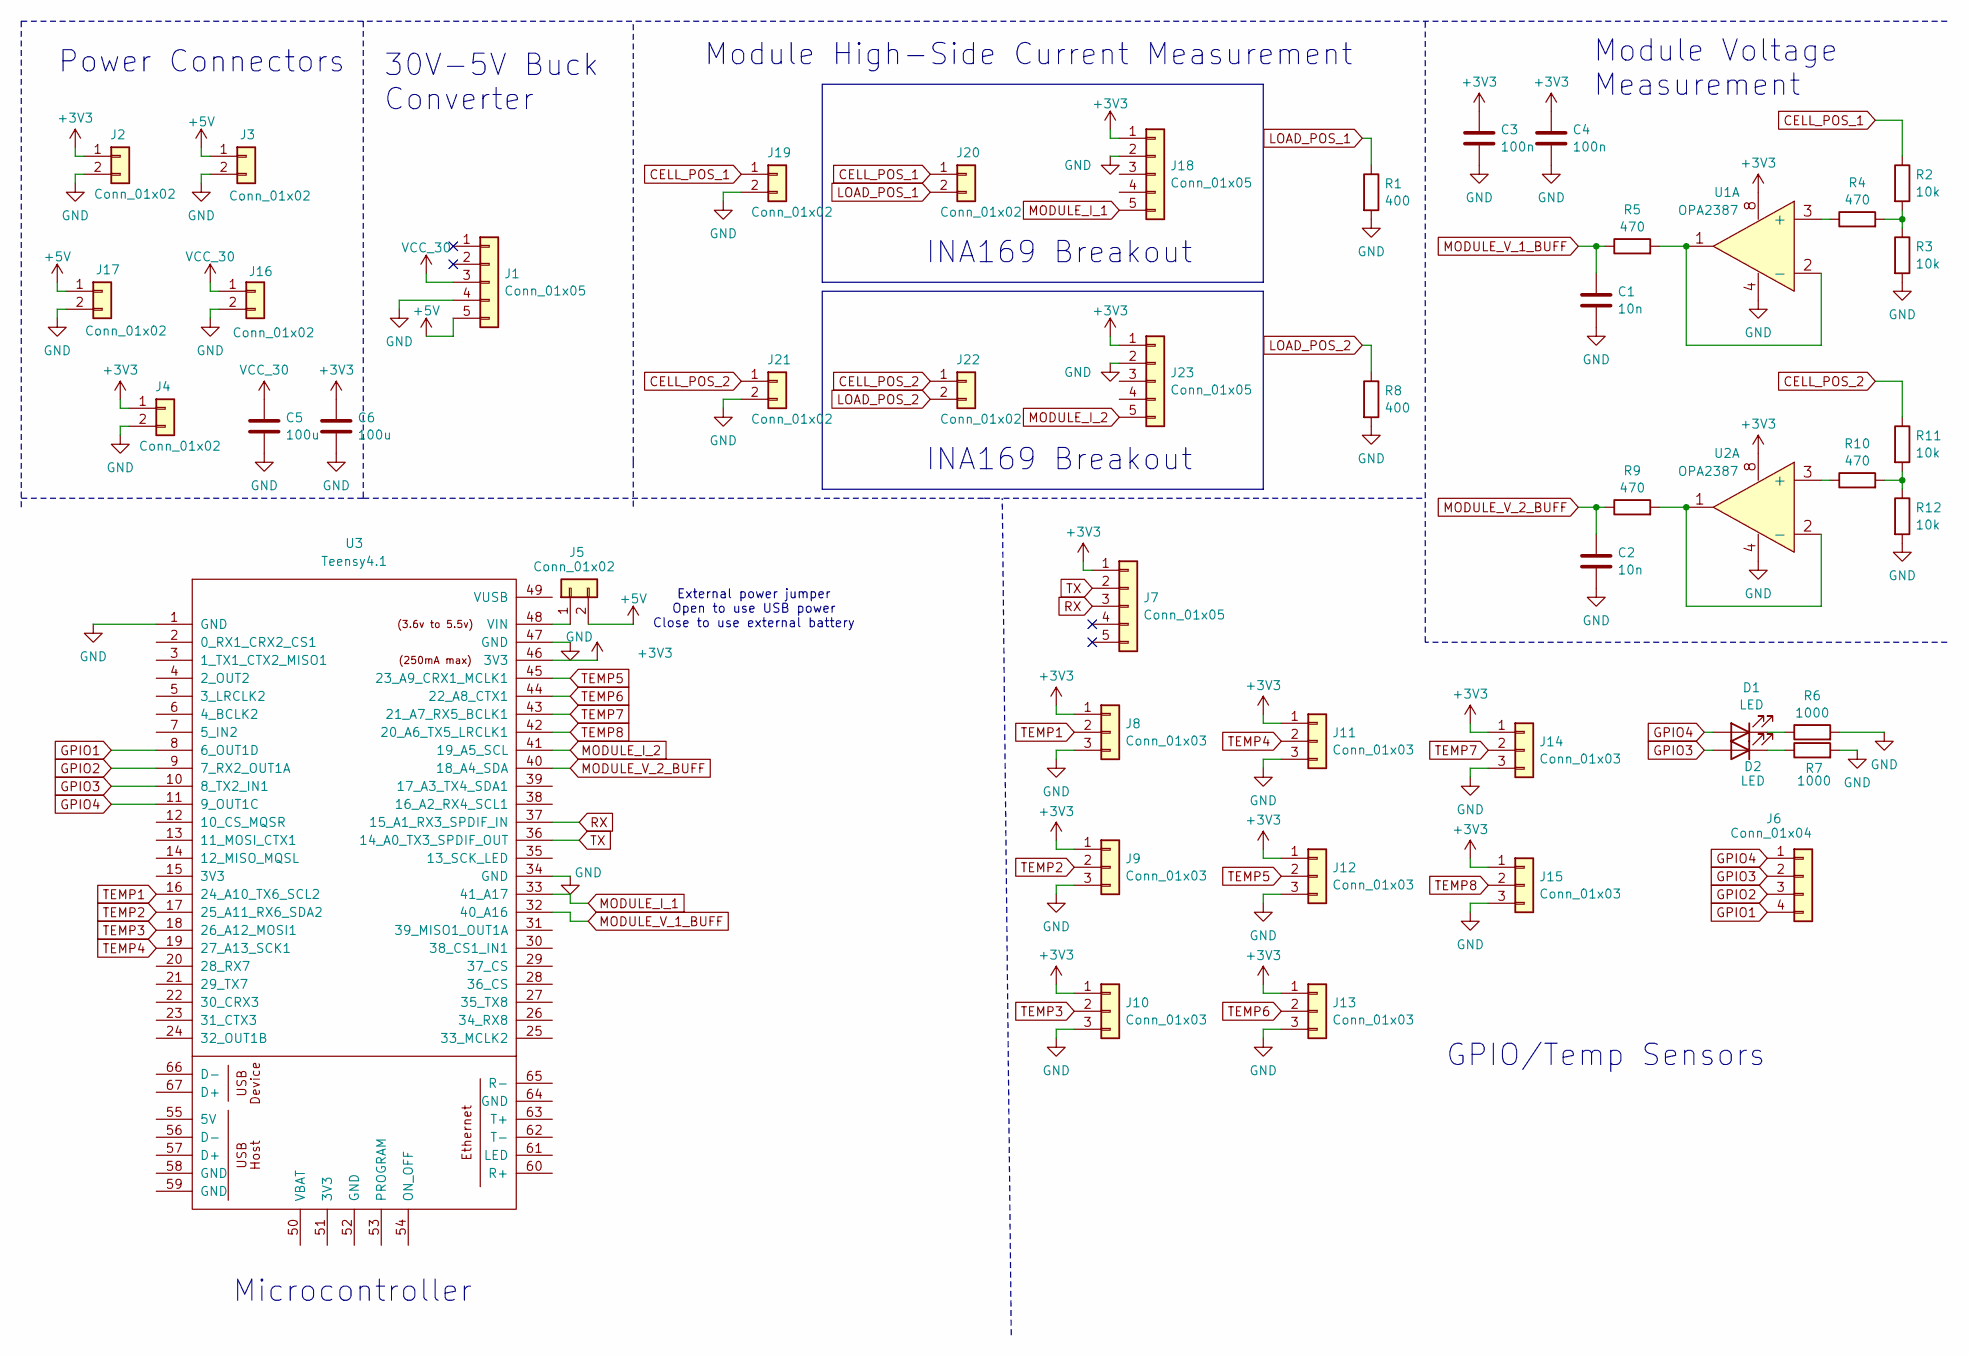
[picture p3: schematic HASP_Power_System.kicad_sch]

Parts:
C1, C2: 10n; C_0805_2012Metric
C3, C4: 100n; C_0805_2012Metric
C5, C6: 100u; C_0805_2012Metric
D1, D2: LED; LED_D1.8mm_W3.3mm_H2.4mm
J1: Conn_01x05; PinHeader_1x05_P2.54mm_Vertical
J2, J3, J4, J17, J19, J21: Conn_01x02; Hirose_DF13C_CL535-0402-2-51_1x02-1MP_P1.25mm_Vertical
J5: Conn_01x02; PinSocket_1x02_P2.54mm_Vertical
J6: Conn_01x04; PinHeader_1x04_P2.54mm_Vertical
J7: Conn_01x05; Molex_PicoBlade_53047-0510_1x05_P1.25mm_Vertical
J8, J9, J10, J11, J12, J13, J14, J15: Conn_01x03; PinHeader_1x03_P2.54mm_Vertical
J16: Conn_01x02; AMASS_XT60-M_1x02_P7.20mm_Vertical
J18, J23: Conn_01x05; 1X05_ROUND_70
J20, J22: Conn_01x02; TERMBLOCK_1X2-3.5MM
R1, R8: 400; Load_Resistor_400ohm
R2, R3, R11, R12: 10k; R_0805_2012Metric
R4, R5, R9, R10: 470; R_0805_2012Metric
R6, R7: 1000; R_0805_2012Metric
U1, U2: OPA2387
U3: Teensy4.1; Teensy41

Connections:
+3V3: C3.1, C4.1, C6.1, J2.1, J4.1, J7.1, J8.1, J9.1, J10.1, J11.1, J12.1, J13.1, J14.1, J15.1, J18.1, J23.1, U1.8, U2.8, U3.46 (3V3)
+5V: J1.5, J3.1, J5.2, J17.1
CELL_POS_1: J19.1, J20.1, R2.1
CELL_POS_2: J21.1, J22.1, R11.1
GND: C1.2, C2.2, C3.2, C4.2, C5.2, C6.2, J1.4, J2.2, J3.2, J4.2, J8.3, J9.3, J10.3, J11.3, J12.3, J13.3, J14.3, J15.3, J16.2, J17.2, J18.2, J19.2, J21.2, J23.2, R1.2, R3.2, R6.2, R7.2, R8.2, R12.2, U1.4, U2.4, U3.1 (GND), U3.34 (GND), U3.47 (GND)
GPIO1: J6.4, U3.8 (6_OUT1D)
GPIO2: J6.3, U3.9 (7_RX2_OUT1A)
GPIO3: D2.2 (A), J6.2, U3.10 (8_TX2_IN1)
GPIO4: D1.2 (A), J6.1, U3.11 (9_OUT1C)
LOAD_POS_1: J20.2, R1.1
LOAD_POS_2: J22.2, R8.1
MODULE_I_1: J18.5, U3.33 (41_A17)
MODULE_I_2: J23.5, U3.41 (19_A5_SCL)
MODULE_V_1_BUFF: C1.1, R5.1, U3.32 (40_A16)
MODULE_V_2_BUFF: C2.1, R9.1, U3.40 (18_A4_SDA)
unnamed: D1.1 (K), R6.1
unnamed: D2.1 (K), R7.1
unnamed: J5.1, U3.48 (VIN)
unnamed: R2.2, R3.1, R4.2
unnamed: R10.2, R11.2, R12.1
unnamed: R4.1, U1.3 (+)
unnamed: R5.2, U1.1, U1.2 (-)
unnamed: R10.1, U2.3 (+)
unnamed: R9.2, U2.1, U2.2 (-)
RX: J7.3, U3.37 (15_A1_RX3_SPDIF_IN)
TEMP1: J8.2, U3.16 (24_A10_TX6_SCL2)
TEMP2: J9.2, U3.17 (25_A11_RX6_SDA2)
TEMP3: J10.2, U3.18 (26_A12_MOSI1)
TEMP4: J11.2, U3.19 (27_A13_SCK1)
TEMP5: J12.2, U3.45 (23_A9_CRX1_MCLK1)
TEMP6: J13.2, U3.44 (22_A8_CTX1)
TEMP7: J14.2, U3.43 (21_A7_RX5_BCLK1)
TEMP8: J15.2, U3.42 (20_A6_TX5_LRCLK1)
TX: J7.2, U3.36 (14_A0_TX3_SPDIF_OUT)
VCC_30: C5.1, J1.3, J16.1

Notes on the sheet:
INA169 Breakout
GPIO/Temp Sensors
Module Voltage Measurement
External power jumper Open to use USB power Close to use external battery
30V-5V Buck Converter
Module High-Side Current Measurement
Power Connectors
Microcontroller

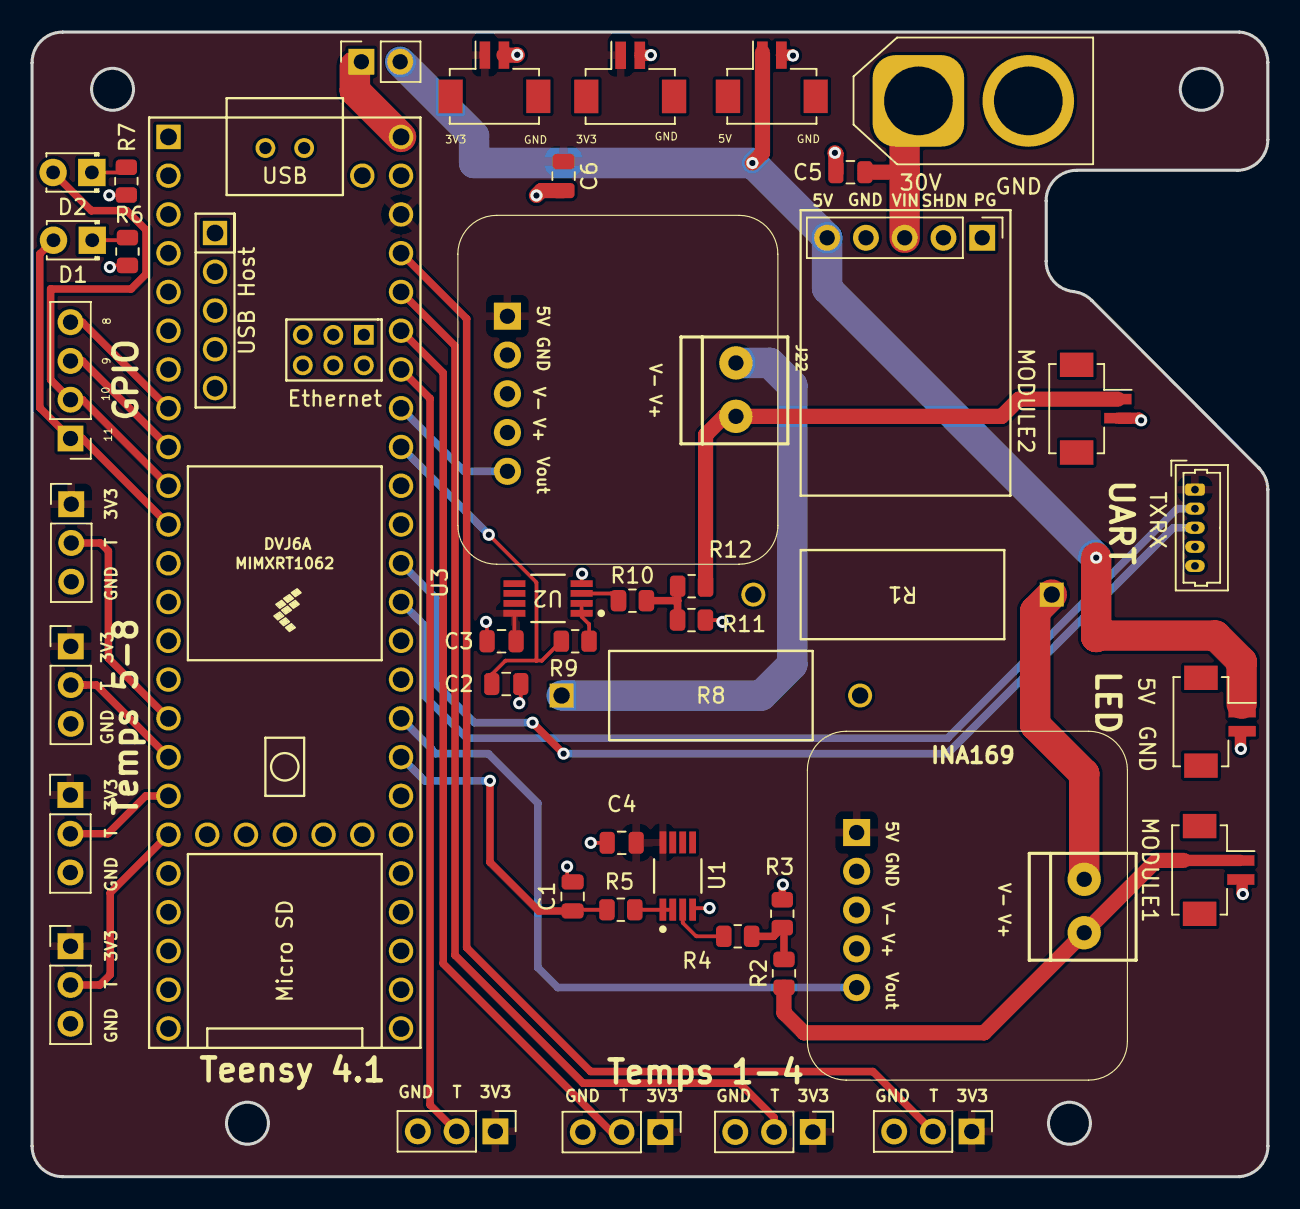
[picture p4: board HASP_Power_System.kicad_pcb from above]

Board: 2 copper layers, 81.0 x 75.0 mm, 46 parts (0 on the bottom side), 35 nets.

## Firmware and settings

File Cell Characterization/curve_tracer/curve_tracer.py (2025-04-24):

import sys
import threading
import time
import tkinter
from tkinter import messagebox
import os
import datetime
import matplotlib.pyplot as plt
import serial
from matplotlib.backends.backend_tkagg import FigureCanvasTkAgg
from matplotlib.figure import Figure
from serial import SerialException
from serial.tools import list_ports
import pandas as pd

SMALL_SIZE = 8
MEDIUM_SIZE = 10
BIGGER_SIZE = 12

plt.rc('font', size=SMALL_SIZE)  # controls default text sizes
plt.rc('axes', titlesize=SMALL_SIZE)  # fontsize of the axes title
plt.rc('axes', labelsize=SMALL_SIZE)  # fontsize of the x and y labels
plt.rc('xtick', labelsize=SMALL_SIZE)  # fontsize of the tick labels
plt.rc('ytick', labelsize=SMALL_SIZE)  # fontsize of the tick labels
plt.rc('legend', fontsize=SMALL_SIZE)  # legend fontsize
plt.rc('figure', titlesize=BIGGER_SIZE)  # fontsize of the figure title
fig_color = '#%02x%02x%02x' % (240, 240, 237)

curve_points_i = [[] for _ in range(6)]
curve_points_v = [[] for _ in range(6)]
curve_points_j = [[] for _ in range(6)]
curve_points_p = [[] for _ in range(6)]
curve_point = [[] for _ in range(6)]
current_panel = 1
current_direction = False

direction_text = ["Reverse", "Forward"]


def clear_plot():
    plot1.clear()


def plot_curve(curve_i):
    global current_direction
    plot1.set_title("Perovskite J-V Curve")
    plot1.set_xlabel("Voltage (V)")
    plot1.set_ylabel("Current Density (mA cm^-2)")
    plot1.plot(curve_points_v[curve_i], curve_points_j[curve_i], label=f"Pixel {curve_i} {direction_text[int(current_direction)]}")
    canvas.draw()


def adc_to_voltage(adc_code, ref_voltage=3.3, max_bin=2**12, gain=0.5, bias_voltage=0.0):
    return (((ref_voltage * adc_code) / float(max_bin - 1)) - bias_voltage) / gain


def adc_to_current(adc_code, gain=50.0, ref_voltage=1.2, max_bin=2**12, sense_res=0.01):
    v = adc_to_voltage(adc_code, ref_voltage=ref_voltage, max_bin=max_bin, gain=1)
    return ((v / gain) / sense_res) * 1000


def read_curve():
    clear_plot()
    overall_summary = pd.DataFrame()
    for dirs in range(2):
        if dirs:
            reverse_trace_direction()
        for i in range(6):
            curve_point[i].clear()
            curve_points_v[i].clear()
            curve_points_i[i].clear()
            curve_points_j[i].clear()
            curve_points_p[i].clear()
            pixel_area_value = float(1 if pixel_area.get() == "" else pixel_area.get())
            if pixel_area_value < 0:
                pixel_area_value = 1e-7
            irradiance_value = float(100 if irradiance.get() == "" else irradiance.get())
            if irradiance_value < 0:
                irradiance_value = 1e-7
            msp430_port.write(b'C')
            start_time = time.time()
            while len(curve_point[i]) != 256:
                reading = ''.join(map(chr, msp430_port.readline().strip())).split(' ')
                curve_point[i].append(int(reading[0]))
                curve_points_v[i].append(adc_to_voltage(abs(int(reading[1])), ref_voltage=3.29, bias_voltage=0.0, max_bin=2**12))
                curve_points_i[i].append(adc_to_current(abs(int(reading[2])), ref_voltage=3.29, gain=200.0, sense_res=0.51, max_bin=2**12))
                curve_points_j[i].append(curve_points_i[i][-1] / pixel_area_value)
                curve_points_p[i].append(curve_points_v[i][-1] * curve_points_i[i][-1])
            temperature_reading = float(msp430_port.readline().strip()) / 100.0
            end_time = time.time()
            sc_cond.config(text=f"Short Circuit: {curve_points_v[i][-1]:.4f} V | {curve_points_i[i][-1]:.4f} mA")
            oc_cond.config(text=f"Open Circuit: {curve_points_v[i][0]:.4f} V | {curve_points_i[i][0]:.4f} mA")
            curve_time.config(text=f"Trace Time: {(end_time - start_time) * 10**3:.4f} ms")
            # temp_label.config(text=f"Panel Temperature: {temperature_reading} \u00b0C")
            plot_curve(i)
            mpp_idx = max(enumerate(curve_points_p[i]), key=lambda x: x[1])[0]
            voc = curve_points_v[i][0]
            isc = curve_points_i[i][-1]
            mpp_v = curve_points_v[i][mpp_idx]
            mpp_i = curve_points_i[i][mpp_idx]
            mpp_p = mpp_v * mpp_i
            ff = (mpp_v * mpp_i) / ((voc * isc) + 1e-7)
            eff = (mpp_p / pixel_area_value) / irradiance_value
            test_time = datetime.datetime.now()
            summary_df = pd.DataFrame(
                [test_time, panel_name.get(), i, pixel_area_value, irradiance_value, temperature_reading, voc, isc, mpp_v, mpp_i, mpp_p, ff, eff, direction_text[dirs]],
                index=["Time", "ID", "Pixel", "Pixel Area", "Irradiance", "Panel Temperature", "Voc", "Isc", "Vmp", "Imp", "Pmp", "FF", "Eff", "Dir"]
            )
            overall_summary = pd.concat([overall_summary, summary_df], axis=1)
            if save_curves.get():
                if panel_name.get() != "":
                    root_dir = os.path.join(output_path, panel_name.get())
                    if not os.path.exists(root_dir):
                        os.mkdir(root_dir)
                    curve_output_path = os.path.join(root_dir,
                                                     f'curve_{temperature_reading}_{get_panel_int()}_{direction_text[dirs]}' + '.xlsx')
                else:
                    curve_output_path = os.path.join(output_path,
                                                     f'curve_{temperature_reading}_{get_panel_int()}_{direction_text[dirs]}' + '.xlsx')
                curve_df = pd.DataFrame([curve_points_v[i], curve_points_i[i], curve_points_j[i], curve_points_p[i]],
                                        index=['Voltage', 'Current', 'Current Density', 'Power']).transpose()
                writer = pd.ExcelWriter(curve_output_path, engine='xlsxwriter')
                frames = {'Summary': summary_df, 'Data': curve_df}
                # now loop thru and put each on a specific sheet
                for sheet, frame in frames.items():  # .use .items for python 3.X
                    frame.to_excel(writer, sheet_name=sheet)
                # critical last step
                writer.close()
            next_panel()
            plot1.legend()
            canvas.draw()
            
            
            #print(i)
            #print(curve_points_v)
            #print(curve_points_i)
            #root_dir = os.path.join(output_path, panel_name.get())
            
            folder_path = 'curves/' + panel_name.get()
            if not os.path.exists(folder_path):
                os.makedirs(folder_path)
            
            if(dirs == 0):
                dir_text = 'Backward'
            else:
                dir_text = 'Forward'
            file_name = os.path.join(folder_path, 'pix_' + str(i) + '_' + dir_text + '.csv')    
      
            with open(file_name, mode='w', newline='', encoding='utf-8') as file:
                for j in range(0, len(curve_points_v[i]) - 1):
                    #print(curve_points_i[i][j])
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

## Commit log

2025-04-24 Initial Characterization
    Characterization 04/24/25 before HAB launch
    [pix_0_Backward.csv, pix_0_Forward.csv, pix_1_Backward.csv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]
2025-04-30 Adding HAB Motherboard Design Files
    [BOM.csv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]
